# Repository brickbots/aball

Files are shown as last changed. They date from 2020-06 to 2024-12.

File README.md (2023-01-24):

# aball
aball - A Buttonless trackball for all

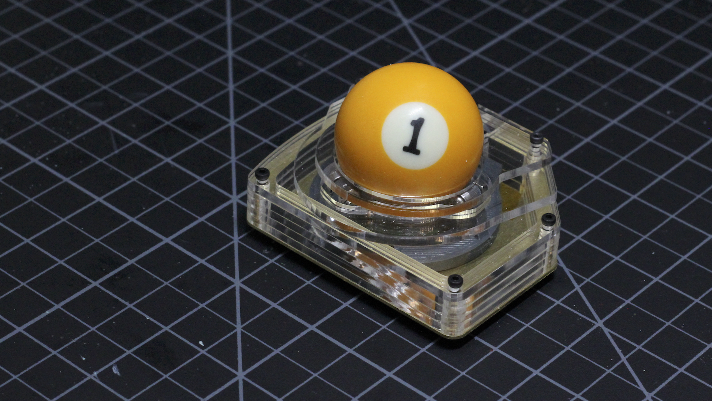
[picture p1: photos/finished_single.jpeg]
aball image The aball


## A trackball with no buttons?
I like keyboards, and my workflow is defintely *keyboard first*.  Tiling window manager, VIM, bash... pretty 
much all the keyboard I can get.  Yet, however hard I try, there is always some need for a pointing device.  
So this is my stab at a trackball for keyboard first workflows.

Why not a mouse?  Well, space... trackballs take up less space.  Which got me thinking, what is the minimum 
footprint for a usable trackball?  I managed to get it down to 60x80mm... you could go even smaller, but I 
wanted some sort of case on it and this particular size sits nicely next to my daily driver, the [Kyria](https://blog.splitkb.com/blog/introducing-the-kyria).

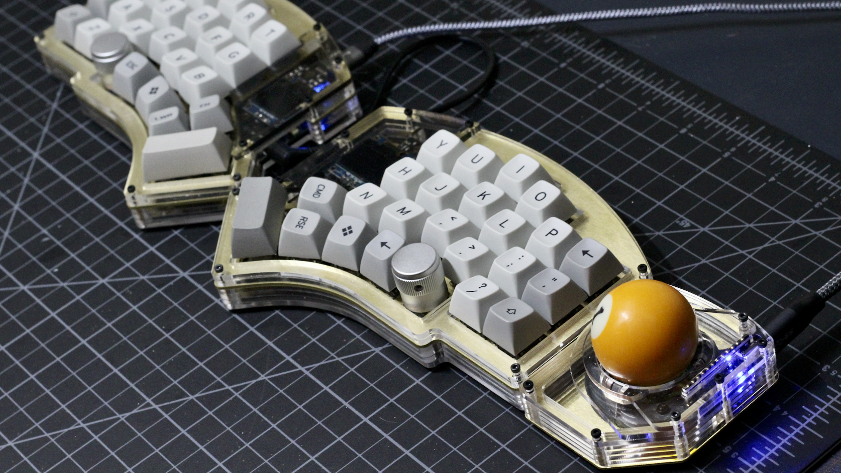
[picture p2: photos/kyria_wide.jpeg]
aball beside Kyria aball with Kyria


In the quest to reduce size, I did away with any buttons.  I have plenty of buttons on my keyboard, and my 
left hand is capable of pressing them when I'm using the aball with my right hand.  Via a layer, I've 
mapped buttons on the home row to:
- F: Left Click
- D: Middle Click
- S: Right Click
- G: Scroll Up
- B: Scroll Down

Scroll up and down are not really needed, but they are pretty handy, even when not using the trackball.  

## Design Info / How it works
Aside from having no buttons and being as small as practical, I wanted the aball to be pretty easy to build and
potentially serve as a jumping off point for other designs.  So I kept these things in mind:

* Readily available parts
* Low cost
* Simple to assemble
* Majority 3d printed if desired
* Supports 38 and 34 mm balls

The design is pretty stripped back, here is a shot of the guts which are self supporting and can be used just as is:

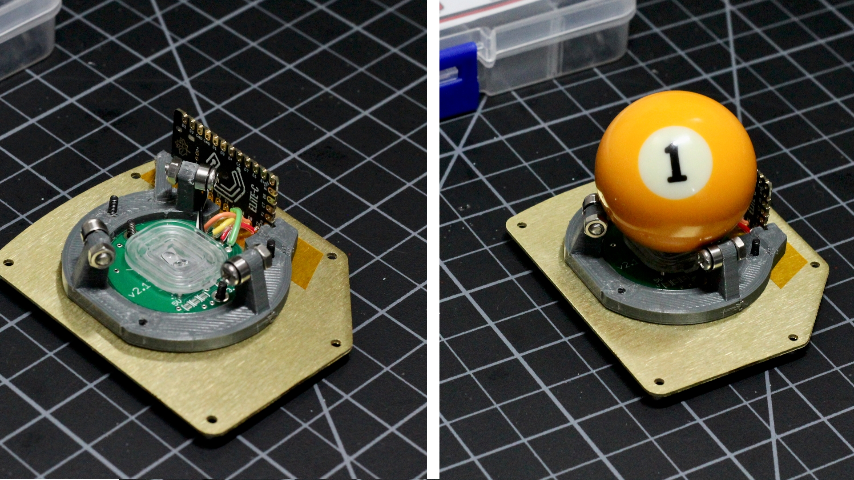
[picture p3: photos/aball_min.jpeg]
aball minimal implementation


The ball sits on a 3d printed frame which holds three roller bearings, and a microcontroller.  The ball moves on top of an optical mouse sensor 
which is connected to the microcontroller. To make the whole thing as close as possible to the desktop, the mouse sensor sticks out
of the bottom of the case, but only a bit and is off the desk due to the rubber feet on the bottom.

### Quick note on roller bearings

If you have not used a trackball with roller bearings before, I think you are in for a treat.  It takes a day or two of good use to 
break them in, but I find them *much* smoother and more enjoyable than static dot type bearings.  You can go cheap here, spending 
less than a dollar for all three of them and they will still be pretty good.  However, a nice set of high quality bearings for RC 
use are not that much more expensive and the quality is definitely higher.

### Firmware

The microcontroller runs firmware based on QMK (Quantum Mechanical Keyboard).  QMK is a fantastic
open source project for keyboard firmware, but it also includes pointing device support.  You can find
the firmware source for the aball here: 
[https://github.com/brickbots/qmk_firmware/tree/aball/keyboards/handwired/aball](https://github.com/brickbots/qmk_firmware/tree/aball/keyboards/handwired/aball)

The minimal implementation is pretty much what you see above and it can be put together for well under $40 if you already have a 3d printer.  From 
there you can either 3d print an enclosure, or use the files here to get some acrylic and metal laser cut for a different look.  I hope that other folks
will adapt these guts and come up with new and clever case options.  Maybe even add buttons on-board :-)

## How can I get one of these?

You can build one yourself!  This repo contains design files, build guides, and a parts list so you can build your own **aball** if you
so choose.  If you do, please drop me a note at rich@brickbots.com.  All information here is provided as-is
for your personal use and is released under a specific Creative Common license which lets you use them for 
non-commercial use.  Please see the included LICENSE file for details.

If you are ready to learn more, or even get started on your own aball, click below to keep exploring

* [Build Guide](./docs/bg_getting_started.md)
* [Parts list (BOM)](./docs/bom.md)

Thanks and email with any questions to suggestions!

<a href='https://ko-fi.com/brickbots' target='_blank'>Buy Me a Coffee at ko-fi.com

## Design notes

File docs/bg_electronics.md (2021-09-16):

# Buile Guide - Electronics

* [Getting Started](../docs/bg_getting_started.md)
* Electronics
* [Structural Assembly](../docs/bg_structure.md)
* [Acrylic Case](../docs/bg_case_acrylic.md)
* [Printed Case](../docs/bg_case_printed.md)
* [Plate Case](../docs/bg_case_plate.md)
* [Parts list (BOM)](../docs/bom.md)

To keep oriented during througout this guide, here is a photo of everything put together without the case.

aball minimal implementation

## Electronics

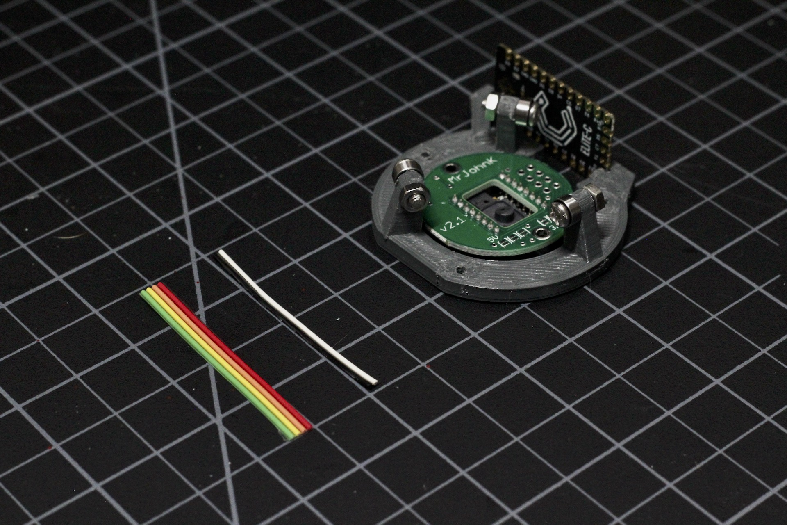
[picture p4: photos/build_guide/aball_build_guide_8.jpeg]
Electronics Arrangement

There are only the two main components and they are connected with just six wires in two groups.  There are two wires for power, and four which carry the SPI interface lines.  

Note the orientation of the MCU and sensor here.  The wires are coming out the BACK of the MCU, and go into the sensor side of the breakout board.

I suggest connecting your MCU and flashing it with the firmware before you start assembly.  This will let you know that it's functional before you spend time soldering.

### Microcontroller

Any pro-micro compatible will work, in this build I'm using an Elite-C as it has a nice robust USB-C connector.  If you do choose something else, you'll need to work out some way to reset the unit. The Elite-C has an onboard reset button and the cases here
have access holes in the proper place to get at it with the case on.  The opening around the plug may also need adjusting, but it should work with many Micro-USB cables if that is what you decide to use.

### Sensor Voltage

If you are using a pro-micro or compatible, it's probably running at 5v.  By default, the sensor
unit is setup to run at 3.3v.  Here is an image, and the description from the vendors website:

Voltage Selection Voltage selection

If you are using Arduino or another similar microcontroller that has a native 5V core voltage, you'll need to activate 5V mode by cutting the tiny traces between the three sets of exposed pads on the 3.3V side of the board and adding three solder bridges to the exposed pads on the 5V side of the board. I recommend an exacto knife. Please be careful not to cut any other nearby traces. Both sets of pads can be found on the backside of the circuit board. This is the most common issue that causes non-communication.

### Wiring

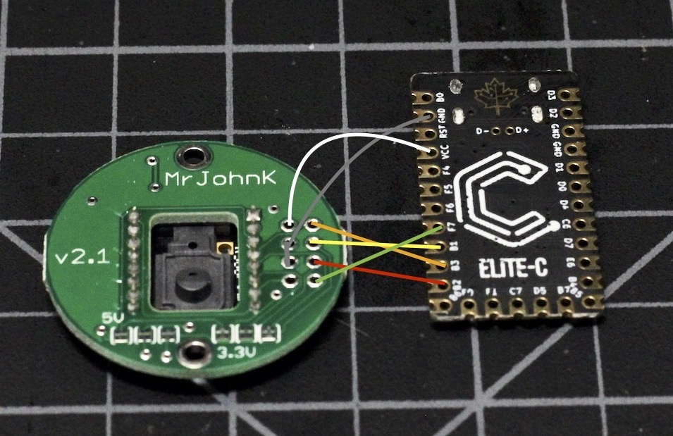
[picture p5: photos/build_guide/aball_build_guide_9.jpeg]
Wiring Wiring Diagram


The diagram above shows the correct connections to make and the suggested pins to use.

* White: VCC +5v
* Grey: Ground.  Note that this is bridged between the analog and digital ground on the sensor
* Red, Orange, Yellow: SPI Bus connections, these can't be relocated
* Green: Select line... any digital pin will do but this is the most convineint location.

You can see the routing of the wires in the image at the top of this page. I suggest stripping both ends of the wires before starting to solder them.  You have some room to work, but keeping the wires short-ish is helpful.  You'll have to solder these wires from the top side sticking out the back of the MCU.

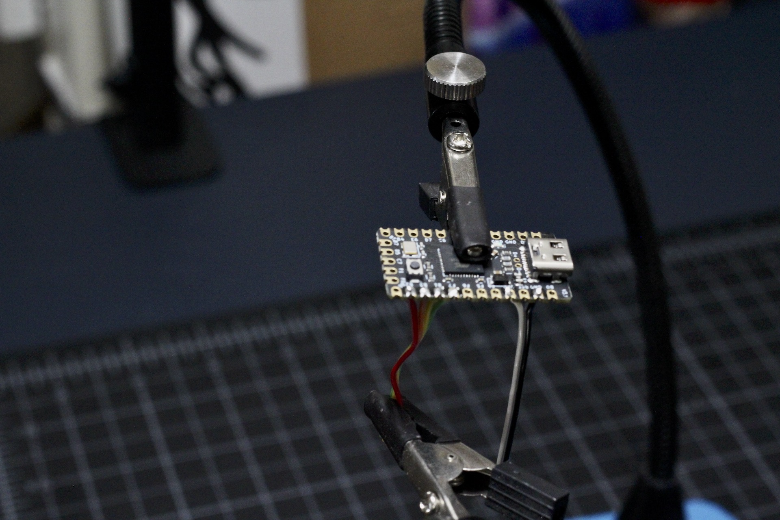
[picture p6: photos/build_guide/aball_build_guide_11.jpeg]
Soldering Soldering from the top


Here is a photo after all the wires attached to the MCU, with a ruler to show how long I made them.

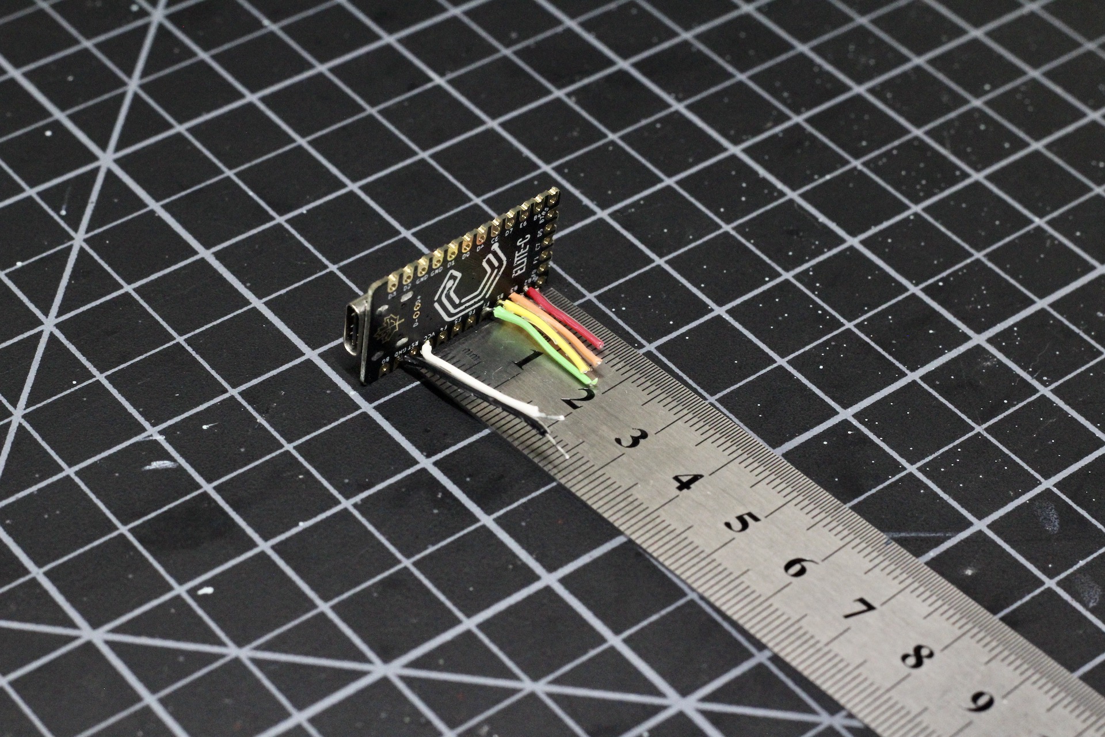
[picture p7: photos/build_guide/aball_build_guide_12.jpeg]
Wire Length Wires for length


Make sure you have the sensor oriented correctly, and follow the wiring diagram to connect the wires to the MCU and finish this step up.

### Testing

This is a great time to plug the MCU back into your computer.  You can place the lens on top of the sensor unit and just run your finger over the sensor.  You should see the cursor on screen move.  If so, you are all set to go with the mechanical assembly!

* [Structural Assembly](../docs/bg_structure.md)

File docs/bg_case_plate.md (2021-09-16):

# Build Guide - Plate Case

* [Getting Started](../docs/bg_getting_started.md)
* [Electronics](../docs/bg_electronics.md)
* [Structural Assembly](../docs/bg_structure.md)
* [Acrylic Case](../docs/bg_case_acrylic.md)
* [Printed Case](../docs/bg_case_printed.md)
* Plate Case
* [Parts list (BOM)](../docs/bom.md)

To keep oriented during througout this guide, here is a photo of everything put together without the case.

aball minimal implementation

### Parts List

For the plate version of the case, you'll need three pieces in total.  You can find all the .dxf
files in the /case/laser_cut_plate. You can use metal, acrylic, wood... basically any material.  1.5mm
thickness works great, but you can go a bit thicker/thinner and everything should still work.

* 1 x middle.dxf
* 1 x top.dxf
* 1 x bottom.dxf

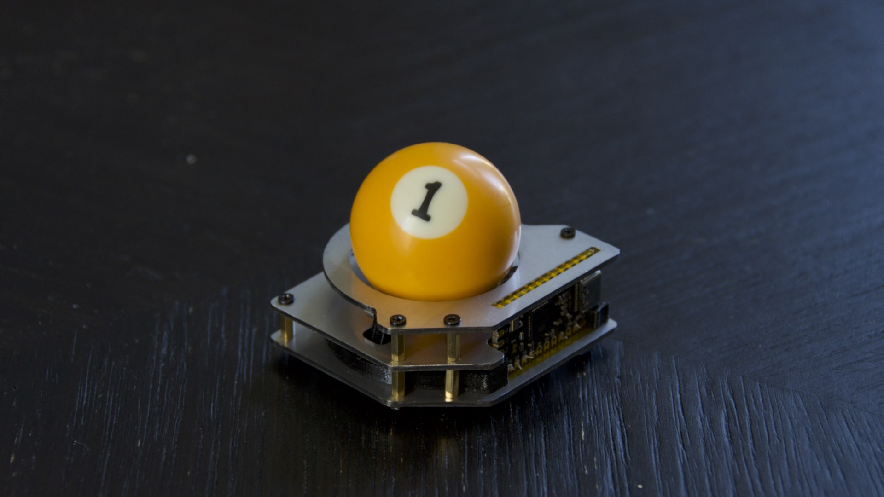
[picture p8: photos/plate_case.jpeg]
Plate Case Sooo metallic!


You'll need m2 standoffs and screws.  The middle layer must be put in plate BEFORE the bearings!  It's 
also much easier to install the lens before the middle layer is installed.

*NOTE:* Don't forget to use insulating tape on the Elite-C along the top 
and on the bottom plate to prevent shorting!

There ya go! Drop in the ball and plug it in.  Feel free to 
contact me with any questions on building, flashing or aquiring parts.  If you do build on of these
I'd love to see it.

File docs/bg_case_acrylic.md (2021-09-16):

# Build Guide - Acrylic Case

* [Getting Started](../docs/bg_getting_started.md)
* [Electronics](../docs/bg_electronics.md)
* [Structural Assembly](../docs/bg_structure.md)
* Acrylic Case
* [Printed Case](../docs/bg_case_printed.md)
* [Plate Case](../docs/bg_case_plate.md)
* [Parts list (BOM)](../docs/bom.md)

To keep oriented during througout this guide, here is a photo of everything put together without the case.

aball minimal implementation

### Parts List

For the acrylic version of the case, you'll need seven 3mm layers in total, not including the base piece
which can either be 3d printed using the STL in the /case/printed directory, or laser cut from 1.5mm 
metal or acrylic.
You can find all the .dxf
files in the /case/laser_cut_stacked directory.  I use Ponoko, and these files are already scaled 
and ready to go.  

If you use elite-c MCU's there is a reset button on the top of the board.  These cases have an 
access hole to reach this button from the side.  That's the reason for the two different 
middle layers.  If you don't want this hole, just use four of the layer A's.  Here is the cut list 
for the cases as pictured with reset hole:

* 2 x middle_a.dxf - Middle piece with no side hole
* 2 x middle_b.dxf - Middle piece with side reset hole
* 1 x top_a.dxf
* 1 x top_b.dxf
* 1 x top_c.dxf

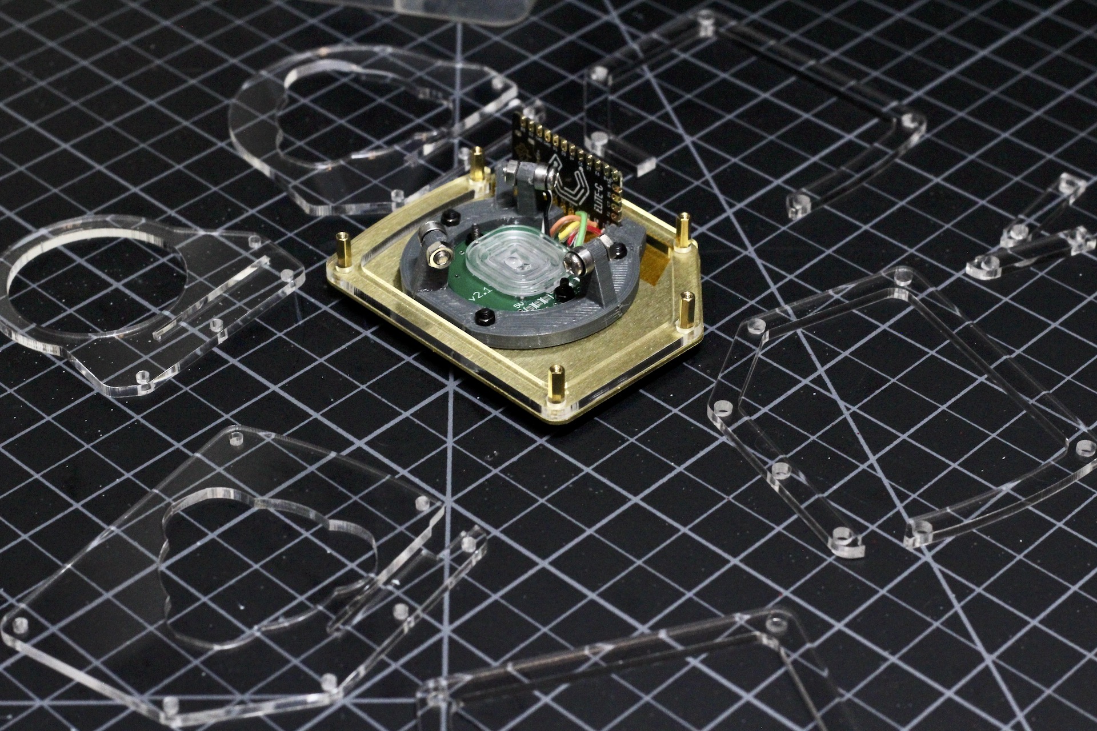
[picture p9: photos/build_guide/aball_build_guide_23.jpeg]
Layers everywhere Layers, Layers!


Peel any protective film off the pieces and stack them up!  Put the two middle_b pieces between the two
middle_a pieces and the gap should line up with the reset button on the MCU.  Use the various screw lengths to
secure the layers.  

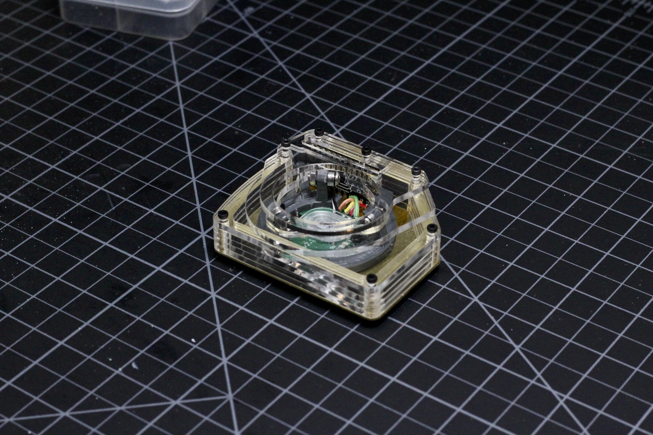
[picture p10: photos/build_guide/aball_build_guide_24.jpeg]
All Built All done


There ya go!  Make sure you seat the lens properly, drop in the ball and plug it in.  Feel free to 
contact me with any questions on building, flashing or aquiring parts.  If you do build on of these
I'd love to see it.

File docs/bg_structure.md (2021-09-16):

# Build Guide - Structural Assembly

* [Getting Started](../docs/bg_getting_started.md)
* [Electronics](../docs/bg_electronics.md)
* Structural Assembly
* [Acrylic Case](../docs/bg_case_acrylic.md)
* [Printed Case](../docs/bg_case_printed.md)
* [Plate Case](../docs/bg_case_plate.md)
* [Parts list (BOM)](../docs/bom.md)

To keep oriented during througout this guide, here is a photo of everything put together without the case.

aball minimal implementation

### Print Frame

You'll need to print one of the vertical_frame files depending on your micro controller and ball size:
* vertical_frame_rev3_38mm.stl - For 1.1mm thick MCUs (such as the Elite-C rev3 or clone pro-micros) and a 38mm ball.  This is what the prototype is based on and is pictured in the build guide.
* vertical_frame_rev4_38mm.stl - For 1.6mm thick MCUs (such as the Elite-C rev4) and a 38mm ball
* vertical_frame_rev4_38mm.stl - For 1.6mm thick MCUs (such as the Elite-C rev4) and a 34mm ball

It lays flat on the bed and will not require any supports.  It's
pretty small, so you might as well go 100% infill.  Depending on your print quality, you might need to drill out the
holes to fit the screws through.  

### Mount Bearings

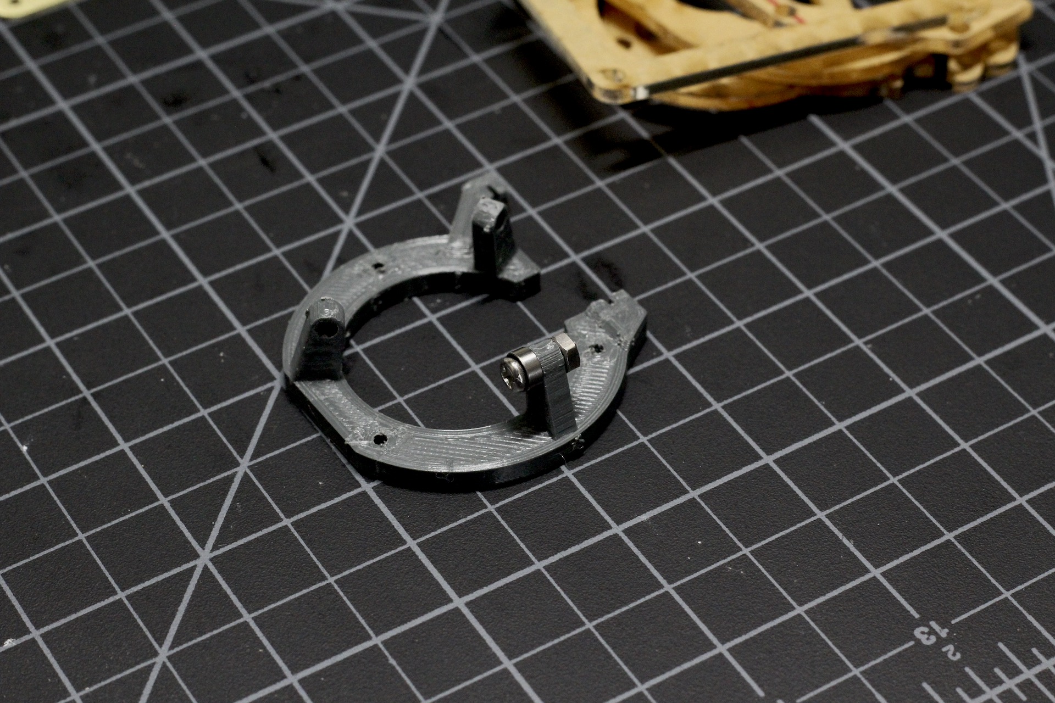
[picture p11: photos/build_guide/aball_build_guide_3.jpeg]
Partially Mounted Bearings Mounted Bearings


Use the M3 round head bolts and nuts to secure the bearings to the frame.  The mount for each bearing is offset so that 
the roller bearings contact the ball properly.  Each bearing needs to be mounted on the clockwise side of the support.
Check the photos if you have any questions.  You can secure these finger tight.

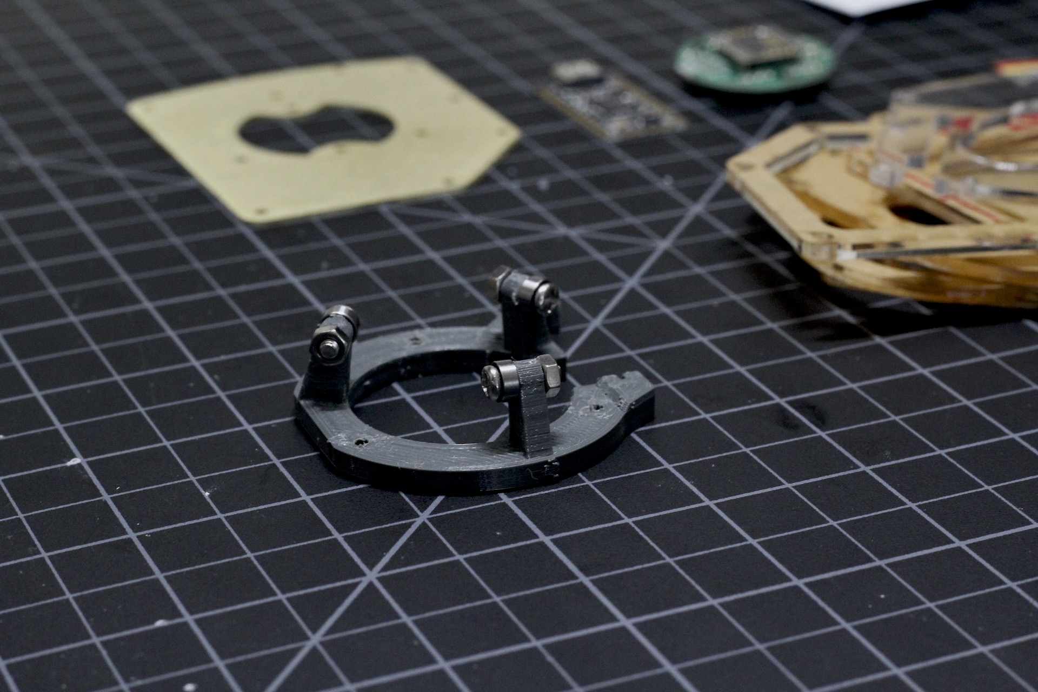
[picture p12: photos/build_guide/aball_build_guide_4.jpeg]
Mounted Bearings


Once they are in place, set the ball on top and everything should roll pretty smoothly.  

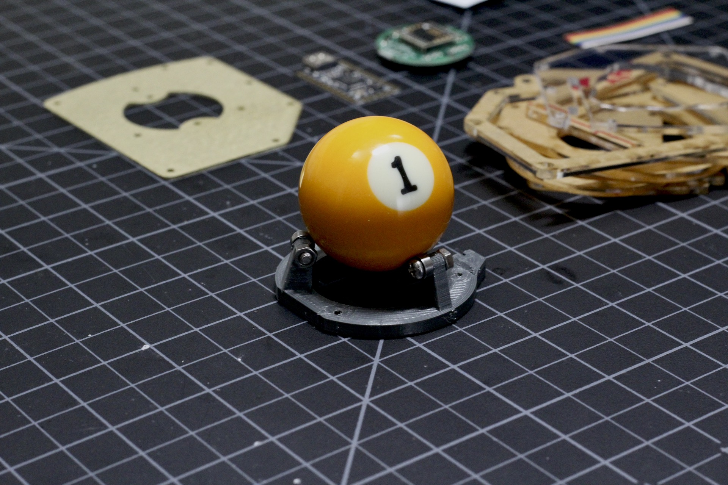
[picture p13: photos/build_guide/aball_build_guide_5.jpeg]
Testing the roll


You can adjust the tightness of the nuts if they are binding.  The bearings will take some time to break in,
so don't be too concerned if they are a bit scratchy, just check that they roll freely.

### Prepare the base

For the base, you can either 3d print the file bottom.stl in the case/printed folder or get the bottom laser 
cut from metal using the bottom.dxf in either of the case/laser_cut folders.  It should be about 1.5mm thick either way.  Since the sensor sticks out of
bottom of the case slightly to reduce to overall height, you'll need to put feet on it before continuing assmbly.

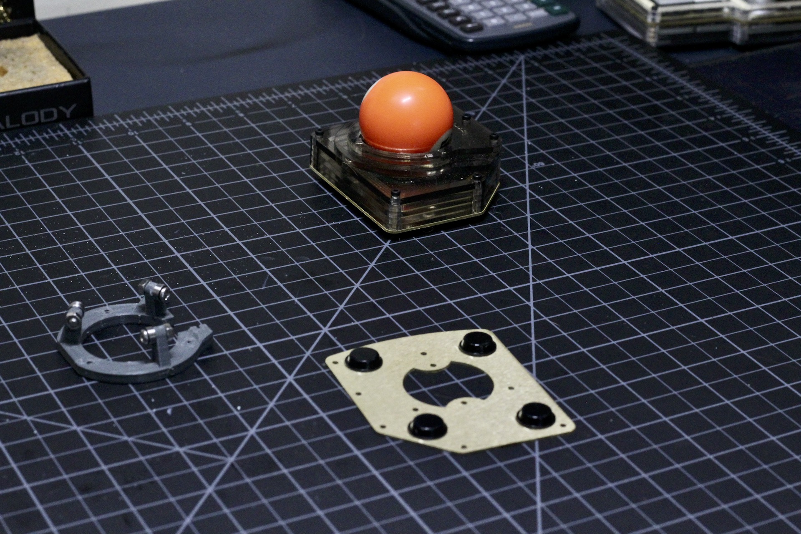
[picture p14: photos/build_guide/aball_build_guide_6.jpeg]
Feet Placement Feet placement


If you are using a metal base, it's a good idea to put down a layer of insulation using either Kapton or electrical tape.  Here's
a photo showing the areas where contact might happen and that should be insulated.  

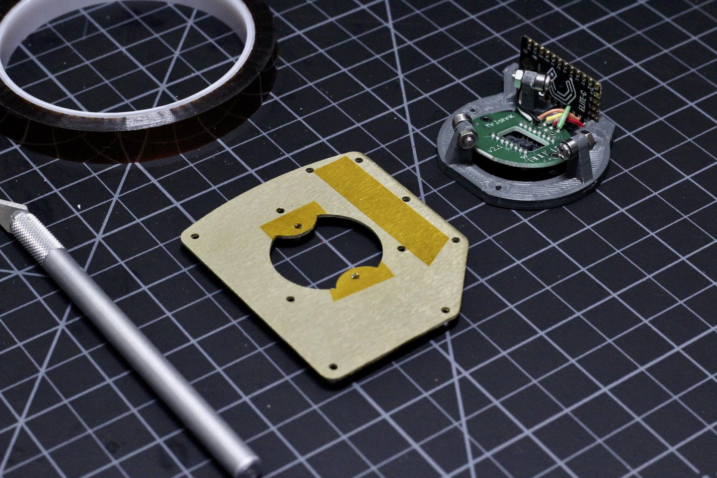
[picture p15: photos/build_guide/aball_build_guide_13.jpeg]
Insulation Tape Placement


### Fit the MCU to the frame

The MCU should friction fit in the slots as show in the photo above and the detail below.  Depending on your printer, you might
need to file these slightly.  You can see above how I routed the wires, but it depens on how long you ended up making them.  

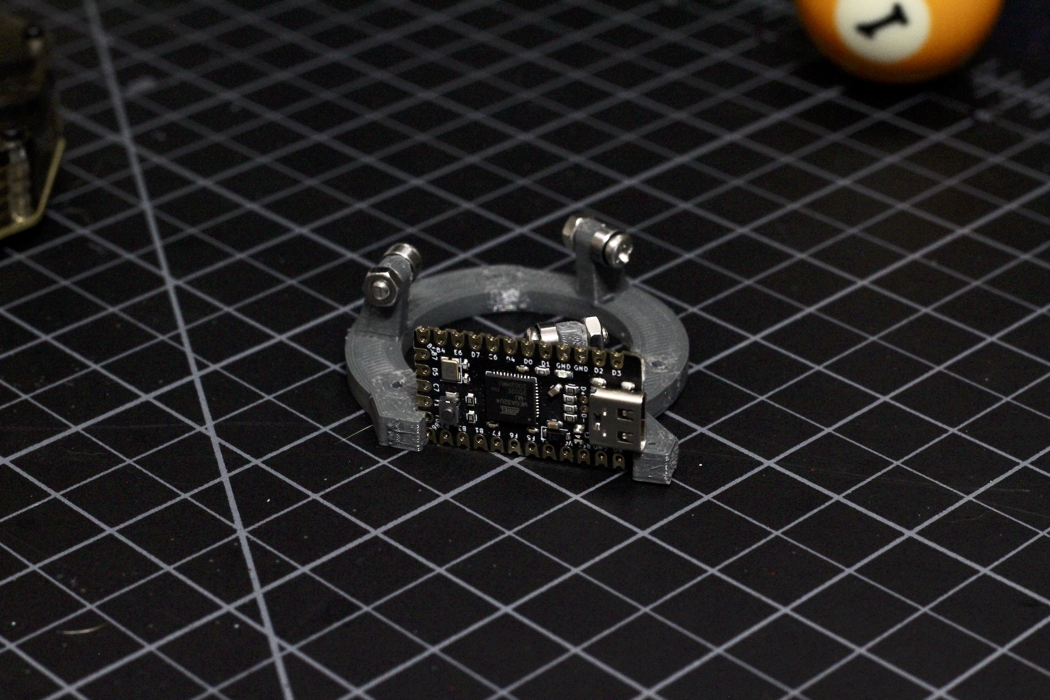
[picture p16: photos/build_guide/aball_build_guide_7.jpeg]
MCU Fitment MCU Fitted on the frame


### Secure the Frame / Sensor

Both the frame and the sensor mount on bolts inserted from the bottom.  The length is not overly critical here, just make sure
they are not soooo long that they rub on the ball.  Use the nuts to secure everything together.  The photo below shows the 
three bolts that hold the frame and the two bolts that hold the sensor.

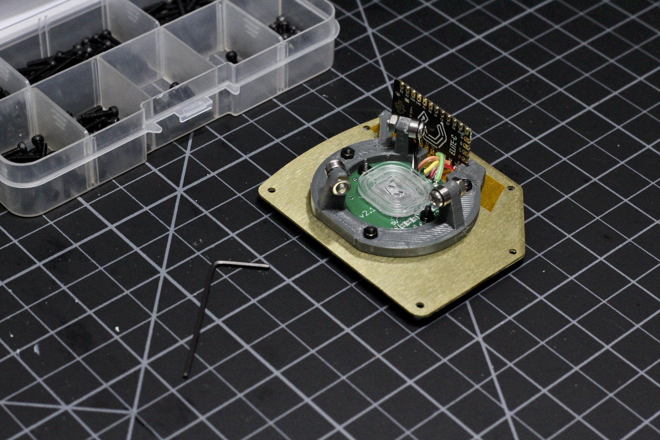
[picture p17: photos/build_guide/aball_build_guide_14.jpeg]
Bolt it together


### Prep for the case

No matter which case you use, it's supported/aligned with seven 10mm standoffs.  You can either use the
male/female ones pictured below or you can use the double female ones either work.  You'll want to secure
these to the bottom plate in the provided holes.

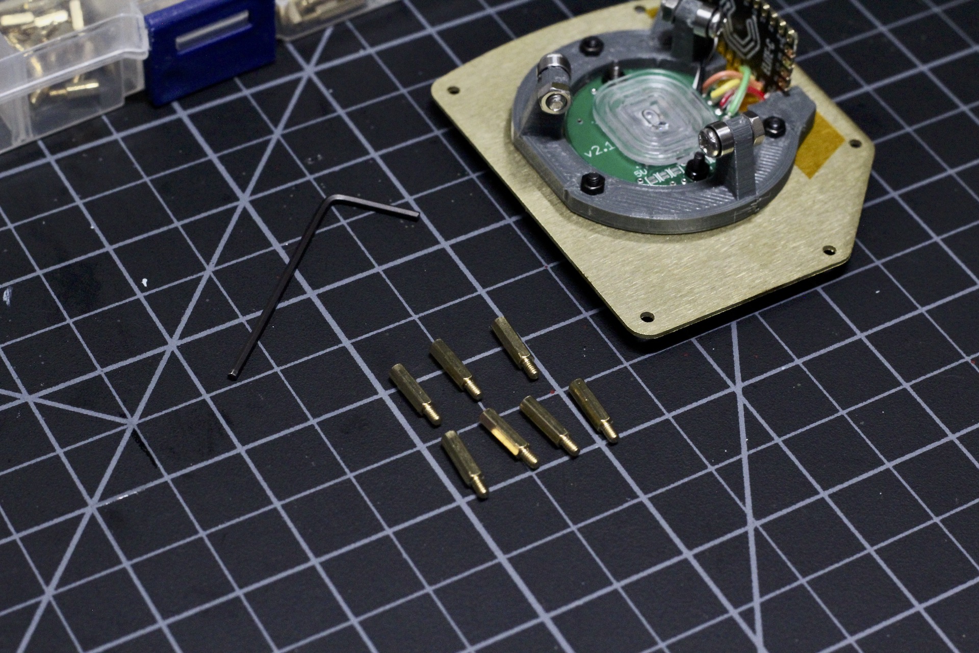
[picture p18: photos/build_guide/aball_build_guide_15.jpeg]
Standoff Setup Standoffs


Here is a view of the underside with the standoffs secured with nuts.

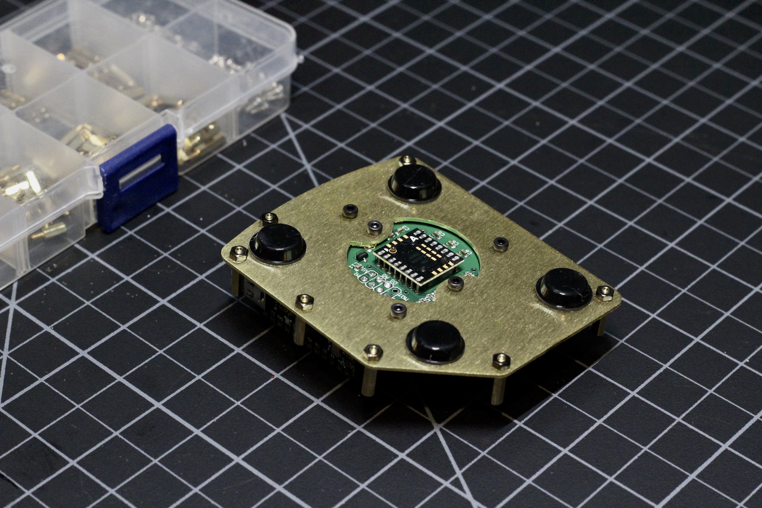
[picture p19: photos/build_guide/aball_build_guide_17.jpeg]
Secured with nuts


Now the structure is done and the case is ready to be installed. 

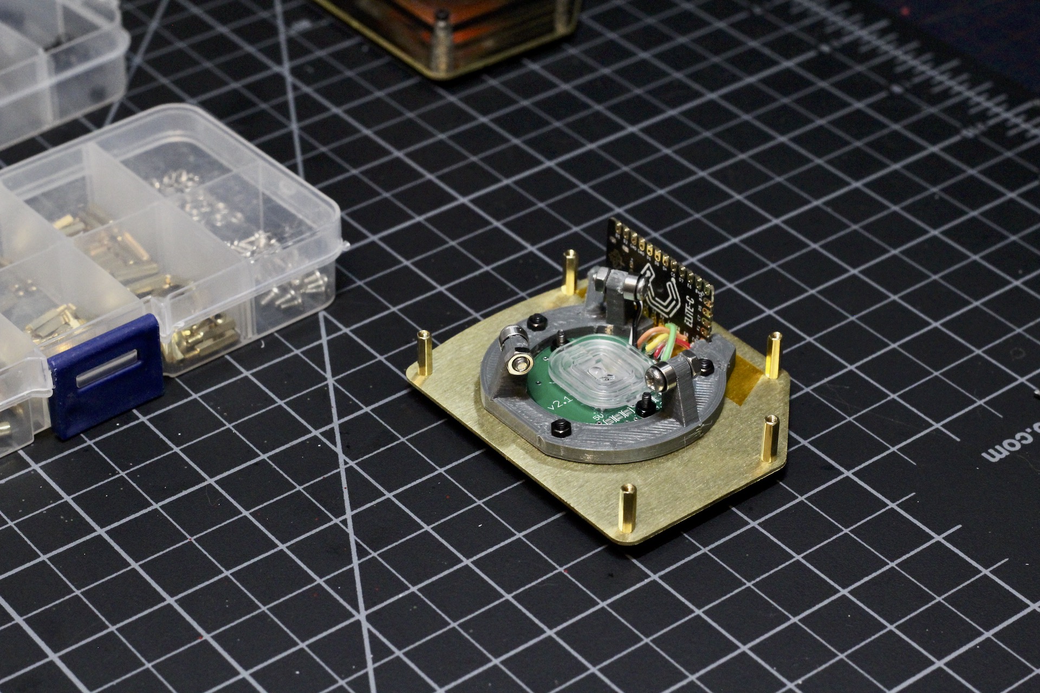
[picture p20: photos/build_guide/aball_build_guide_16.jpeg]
Ready for case Ready for case!


There are two case options available:
* [Acrylic Case](../docs/bg_case_acrylic.md)
* [Printed Case](../docs/bg_case_printed.md)

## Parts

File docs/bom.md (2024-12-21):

# aball - Parts List / BOM

## Minimal Parts List
If you don't want any case at all, here is the stuff you'll need for the guts of an aball.  You'll need to 3d print
the support frame and some sort of bottom if you don't want to use metal.

Quantity|Item|URL
---|---|---
3|3x6x2.5mm Ball Bearing|https://www.amazon.com/gp/product/B014LT87HS
3|M3 Nuts|
3|M3 Bolts, round head, 10mm|
5|M2x8 Bolts|
5|M2 nuts |
3|Rubber Feet|
1|Pro Micro Compatible - Elite-C Recommended|
1|ADNS-9800 Laser Motion Sensor Breakout|https://www.tindie.com/products/citizenjoe/adns-9800-motion-sensor/
1|Ball either 38mm or 34mm|https://www.amazon.com/gp/product/B00CEQY0J0 https://www.amazon.com/gp/product/B07BDGSX5X

## Acrylic / Printed case
There are plans in this repo for both a 3d printed, and laser cut acrylic case.  Depending on what case you want, and what you have on hand,
you can substitute some of the M2 hardware.  

Quantity|Item|URL
---|---|---
3|3x6x2.5mm Ball Bearing|https://www.amazon.com/gp/product/B014LT87HS
3|M3 Nuts|
3|M3 Bolts, round head, 10mm|
5|M2x8 Bolts|
4|M2x12 Bolts|
3|M2x6 Bolts|
7|M2 standoff M/F 10mm|
12|M2 nuts |
3|Rubber Feet|
1|Pro Micro Compatible - Elite-C Recommended|
1|Jack Enterprises - ADNS-9800 Laser Motion Sensor Breakout|https://www.tindie.com/products/jkicklighter/adns-9800-laser-motion-sensor/
1|Ball either 38mm or 34mm|https://www.amazon.com/gp/product/B00CEQY0J0 https://www.amazon.com/gp/product/B07BDGSX5X

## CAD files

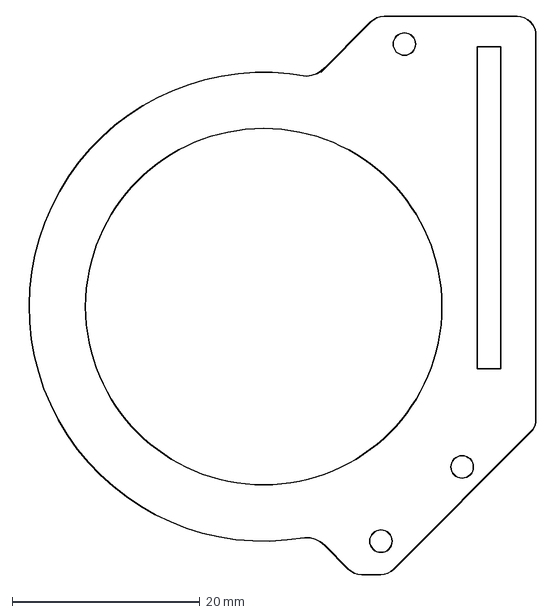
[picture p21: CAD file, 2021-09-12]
case/laser_cut_plate/top.dxf
55.4 x 59.5 mm

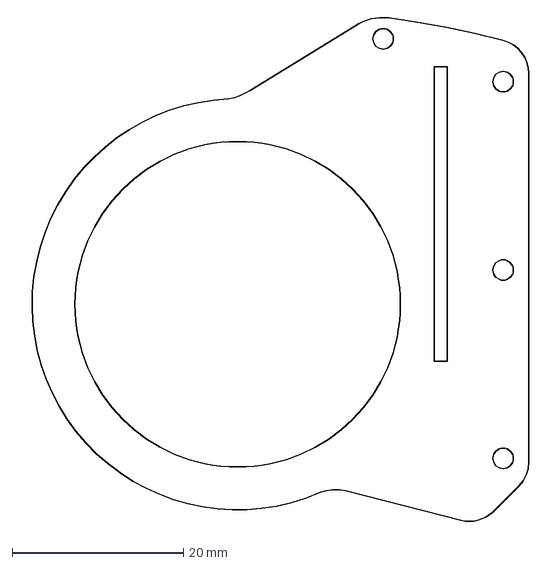
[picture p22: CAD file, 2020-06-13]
case/laser_cut_stacked/top_c.dxf
59.9 x 59.5 mm

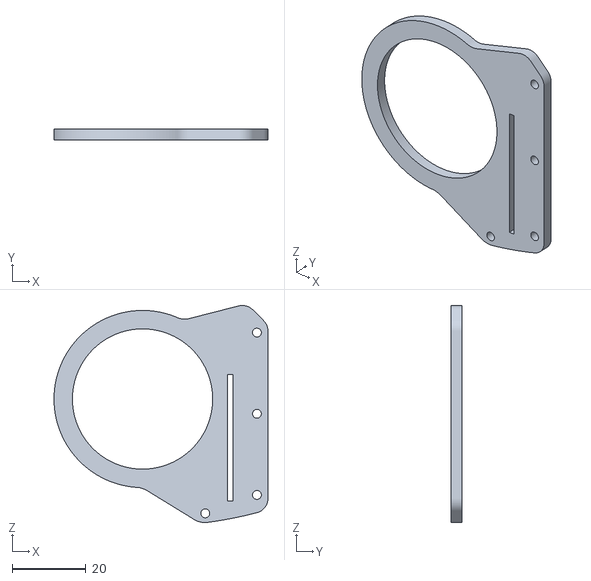
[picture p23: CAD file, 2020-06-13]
case/printed/top_c.stl
58.0 x 2.90 x 58.8

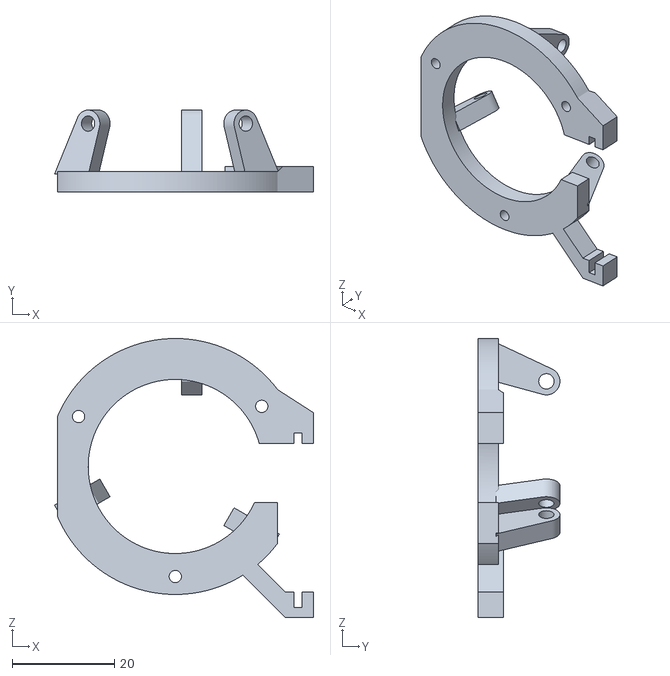
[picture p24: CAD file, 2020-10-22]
vertical_frame_rev4_34mm.stl
50.6 x 16.0 x 54.5

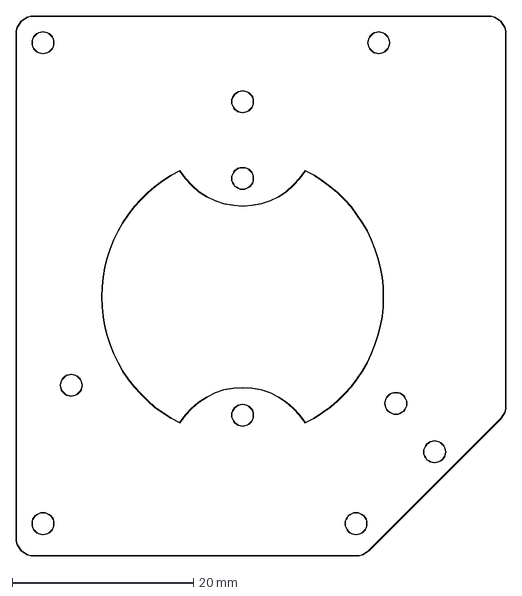
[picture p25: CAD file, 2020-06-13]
case/laser_cut_plate/bottom.dxf
54.0 x 59.5 mm

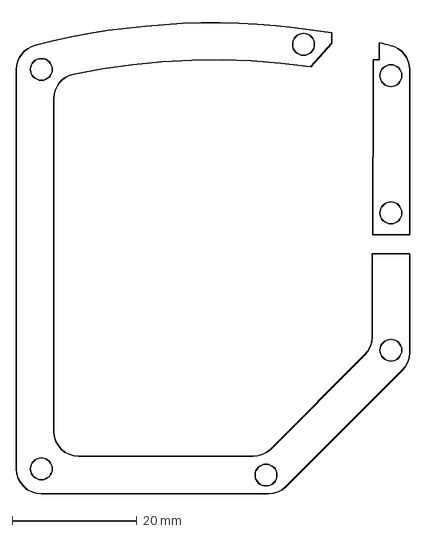
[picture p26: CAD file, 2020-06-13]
case/laser_cut_stacked/middle_b.dxf
63.0 x 76.5 mm

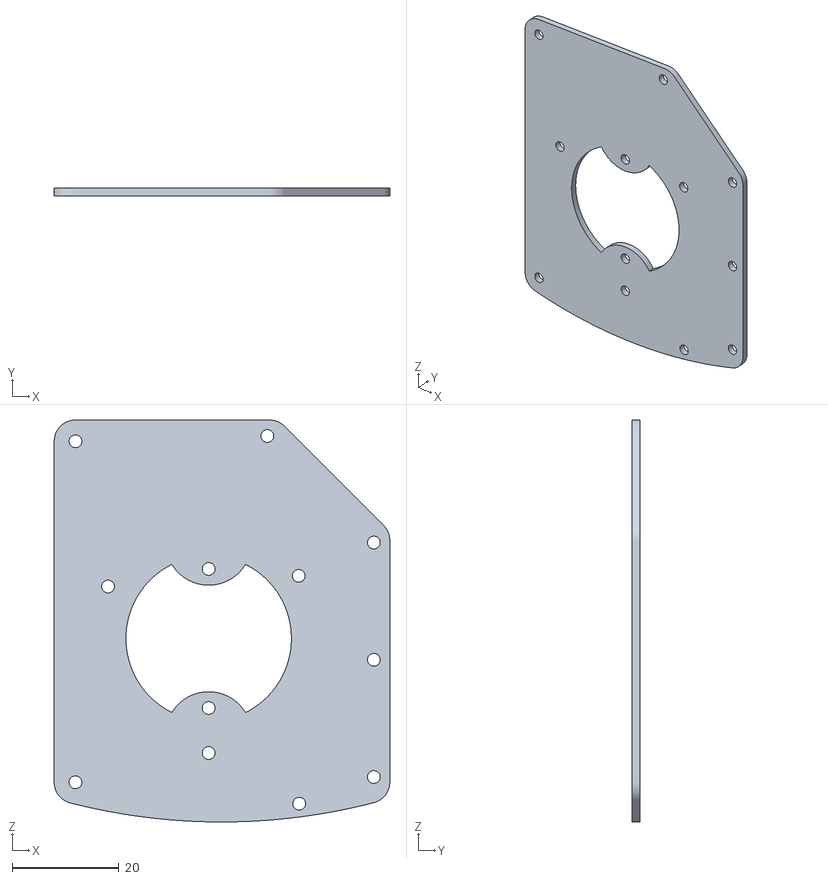
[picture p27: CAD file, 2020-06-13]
case/printed/bottom.stl
63.0 x 1.50 x 75.4

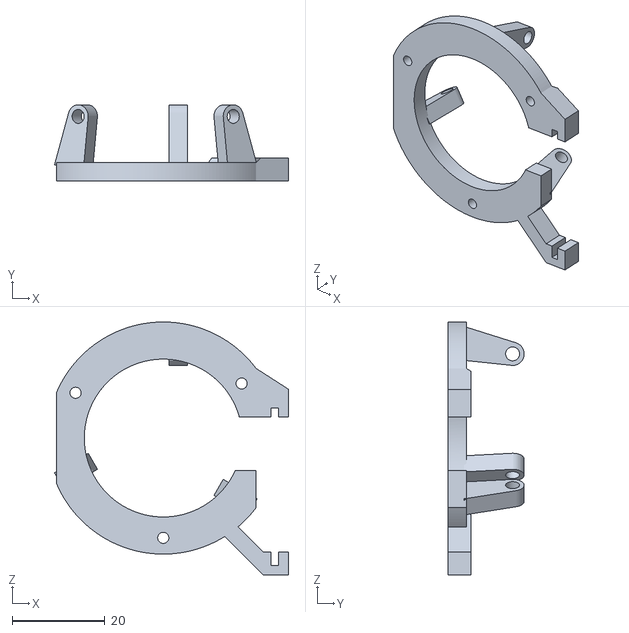
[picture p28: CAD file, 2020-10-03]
vertical_frame_rev4_38mm.stl
50.5 x 16.4 x 54.5

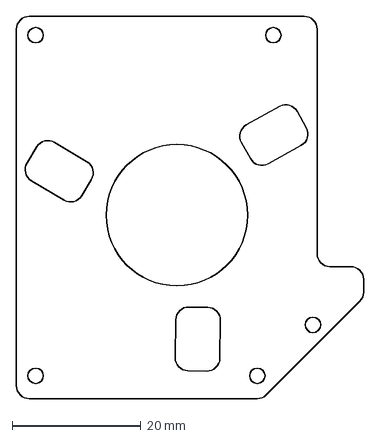
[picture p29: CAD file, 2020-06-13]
case/laser_cut_plate/middle.dxf
54.0 x 59.5 mm

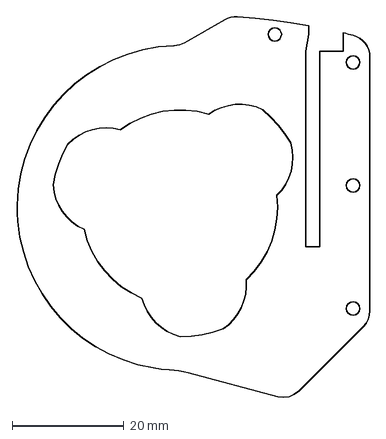
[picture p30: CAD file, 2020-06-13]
case/laser_cut_stacked/top_b.dxf
63.2 x 68.3 mm

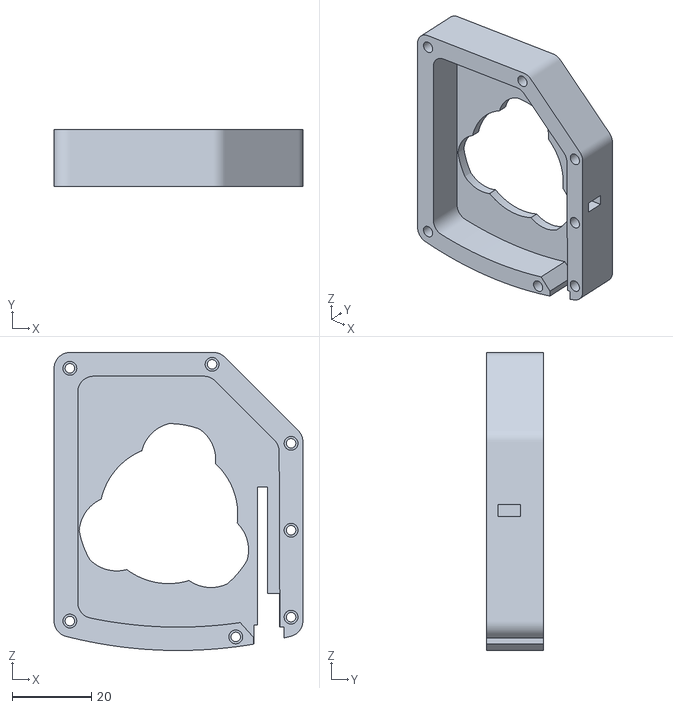
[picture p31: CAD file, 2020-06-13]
case/printed/middle_top_a.stl
63.0 x 14.5 x 75.4

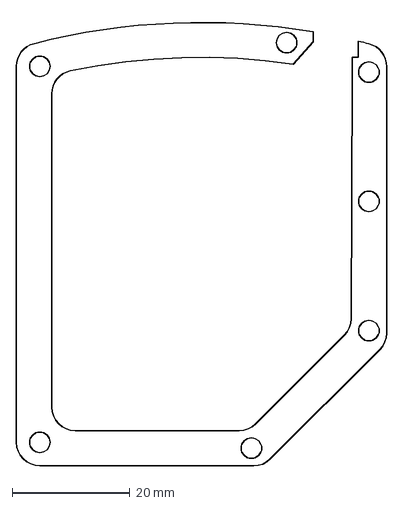
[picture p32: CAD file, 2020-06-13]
case/laser_cut_stacked/middle_a.dxf
63.0 x 76.5 mm

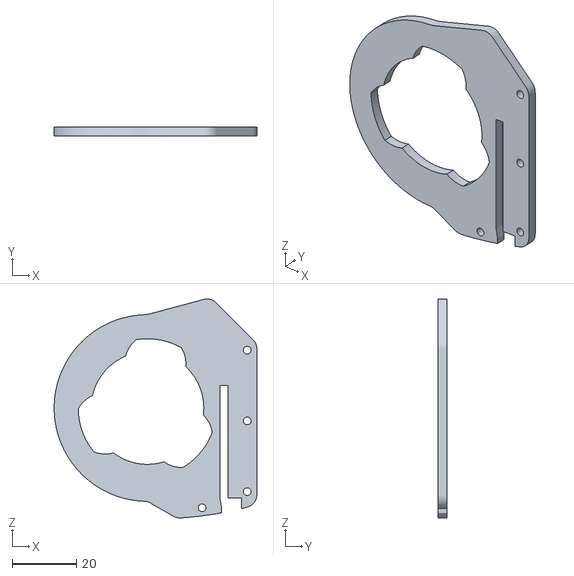
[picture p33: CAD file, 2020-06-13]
case/printed/top_b.stl
63.0 x 2.90 x 68.1

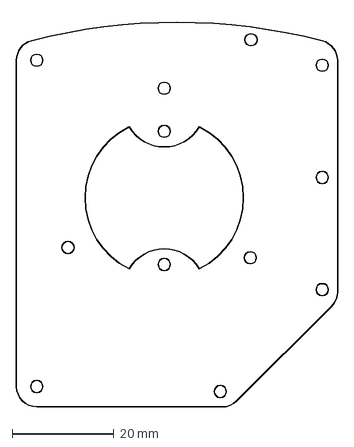
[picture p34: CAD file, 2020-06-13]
case/laser_cut_stacked/bottom.dxf
63.0 x 76.7 mm

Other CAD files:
case/laser_cut_stacked/top_a.dxf
vertical_frame_rev3_38mm.stl
aball_v15.f3d

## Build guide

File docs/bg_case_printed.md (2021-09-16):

# Build Guide - Printed Case

* [Getting Started](../docs/bg_getting_started.md)
* [Electronics](../docs/bg_electronics.md)
* [Structural Assembly](../docs/bg_structure.md)
* [Acrylic Case](../docs/bg_case_acrylic.md)
* Printed Case
* [Plate Case](../docs/bg_case_plate.md)
* [Parts list (BOM)](../docs/bom.md)

To keep oriented during througout this guide, here is a photo of everything put together without the case.

aball minimal implementation

### Parts List

For the printed version of the case, you'll need four pieces in total.  You can find all the .stl
files in the /case/printed.  They should all print easily and don't require supports.  Since they are
pretty much all walls/flat surfaces, you can print with high-infill for weight and it won't take 
much longer.

* 1 x middle_top_a.stl
* 1 x top_b.stl
* 1 x top_c.stl

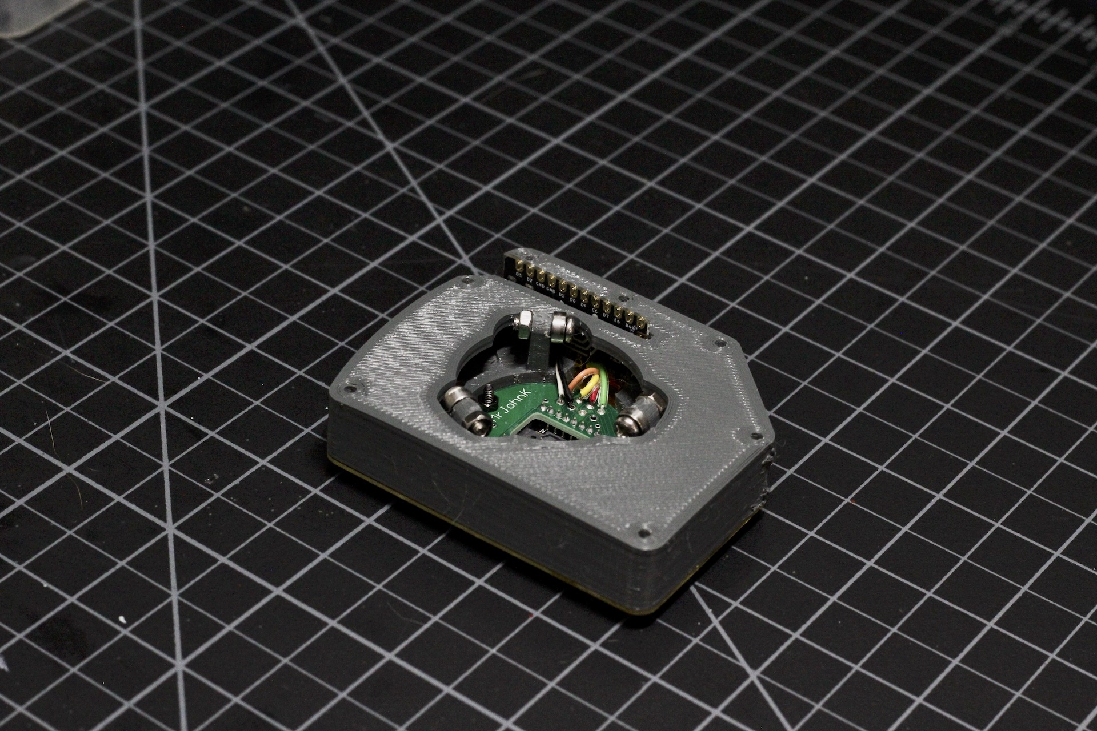
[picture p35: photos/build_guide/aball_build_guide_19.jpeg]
Middle Case Layers, Layers!


The middle_top piece slides over the stand-offs.  Depending on your printer quality/settings 
you might need to drill out some of the holes to the proper diameter.  

To finish up, the two other top pieces stack on top and you can secure everything with the 
various lengths of screws. 

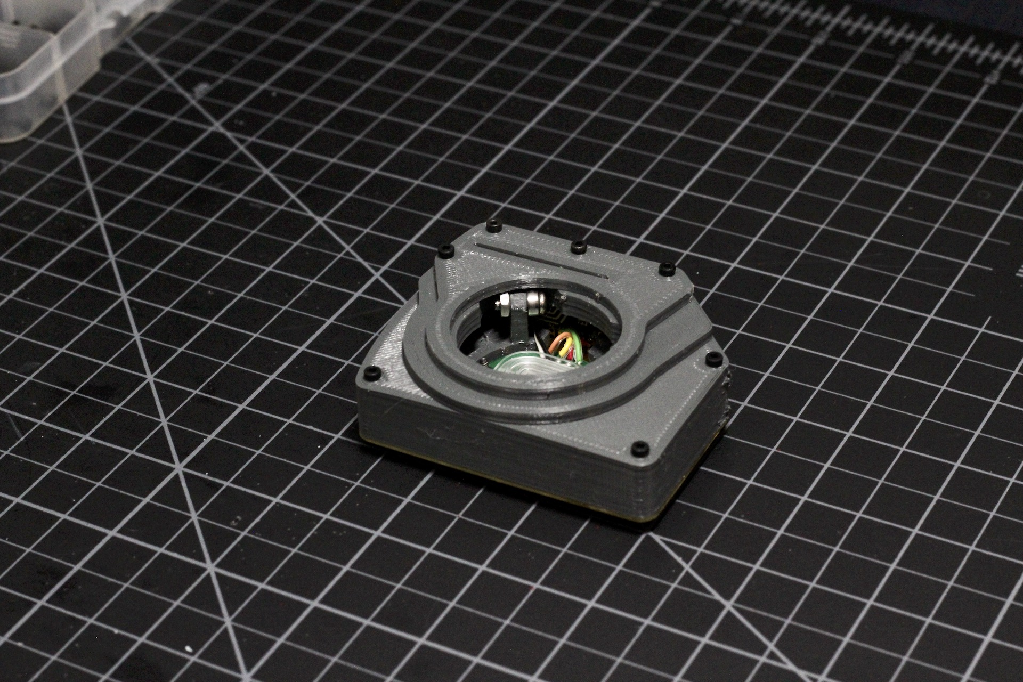
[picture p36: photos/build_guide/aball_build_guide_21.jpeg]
All Built All done


There ya go!  Make sure you seat the lens properly, drop in the ball and plug it in.  Feel free to 
contact me with any questions on building, flashing or aquiring parts.  If you do build on of these
I'd love to see it.

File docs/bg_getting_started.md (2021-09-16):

# Build Guide - Getting Started

* Getting Started
* [Electronics](../docs/bg_electronics.md)
* [Structural Assembly](../docs/bg_structure.md)
* [Acrylic Case](../docs/bg_case_acrylic.md)
* [Printed Case](../docs/bg_case_printed.md)
* [Plate Case](../docs/bg_case_plate.md)
* [Parts list (BOM)](../docs/bom.md)

To keep oriented during througout this guide, here is a photo of everything put together without the case.

aball minimal implementation

## Collect your parts

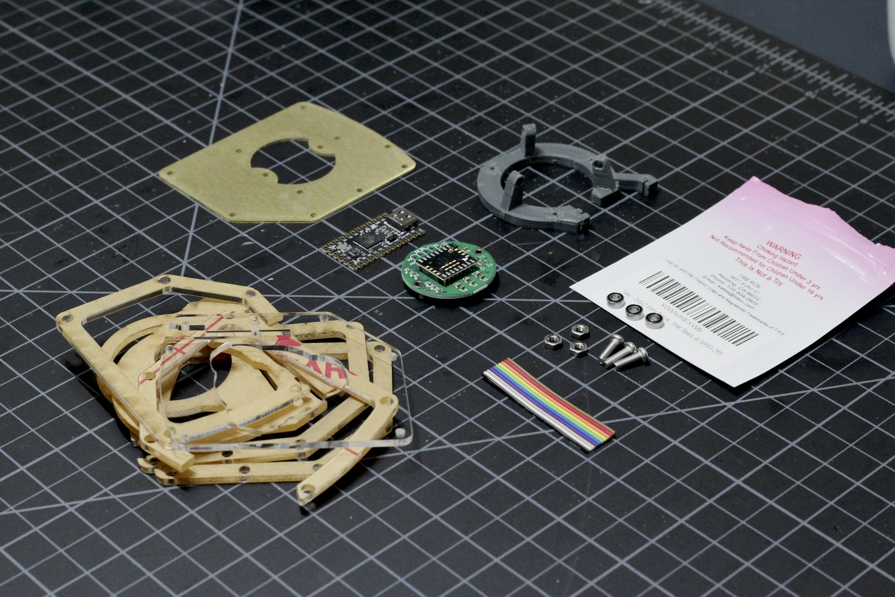
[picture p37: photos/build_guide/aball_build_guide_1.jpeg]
Parts Image The Parts


Here are all the parts required to build an ABall with acrylic case.  See the Parts List above for details.  A case is strictly optional, and I've used protoypes without one....but the bottom plate is essential as it's what everyting else bolts on to.  

In this photo the sensor is upside down, with the lens assembly pointing down.  In most of these other photos 
you'll see this sensor facing upwards, so it can keep an eye on the ball... so to speak.  There is a plastic
lens assembly that only fits on one way.  You don't need to secure this in place at all and you'll see some 
shots with, and some without it.  It's definitely needed for the sensor to work, so don't loose it.

### Bearings and Ball - Your point of contact
I've included information about the bearings in the BOM, but here is a closeup of the ones I prefer.  The price difference is not much for pretty much top of the line, and it's really the biggest determiner of feel apart from the ball itself.  The size I selected is fairly common for RC cars, planes, etc.. so you should be able to find a good variety.

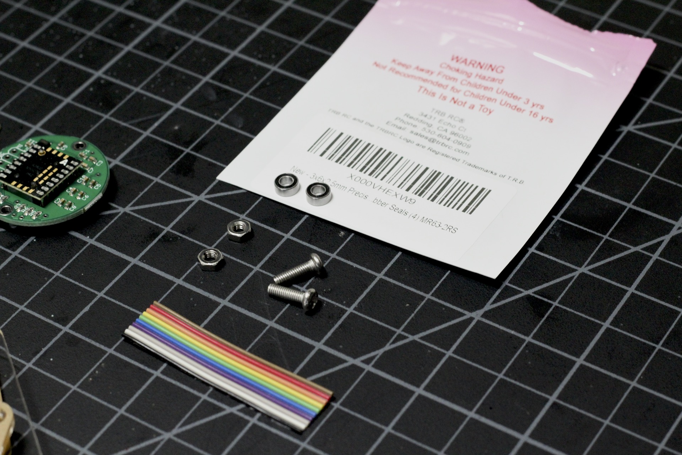
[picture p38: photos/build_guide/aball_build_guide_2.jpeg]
Bearing Closeup RC bearings


As for balls, I've designed this around 38mm balls.  You can go a bit larger, or smaller, and the overall support will work, but cases may not fit properly.  This is a pretty standard size for mini billlard balls, but you an also get full steel ball bearings of this size if you like a heavy roll.  I've tried this, and I can't say I recommend it, but there are plenty of possibilities!  

Now that you have all your pieces together, let's start with the [electronics](../docs/bg_electronics.md)!

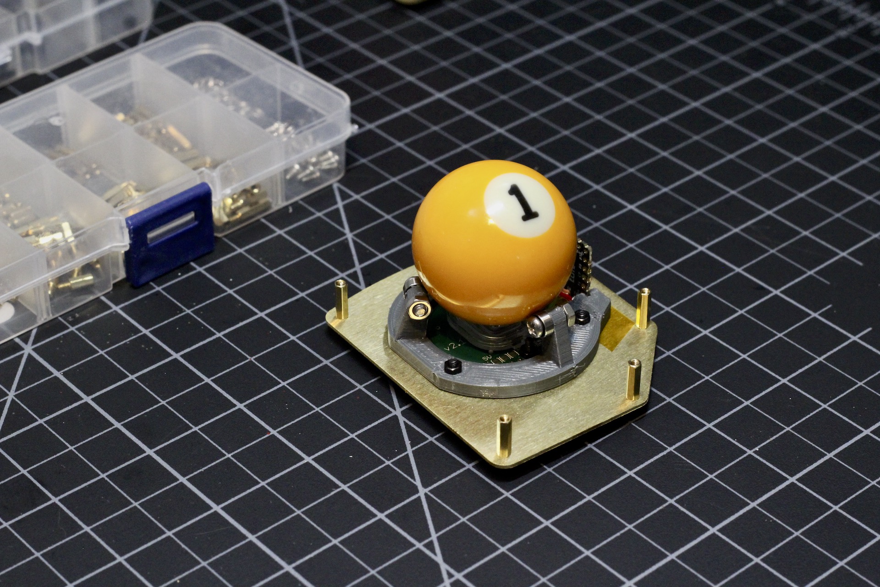
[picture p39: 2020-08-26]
photos/build_guide/aball_build_guide_18.jpeg

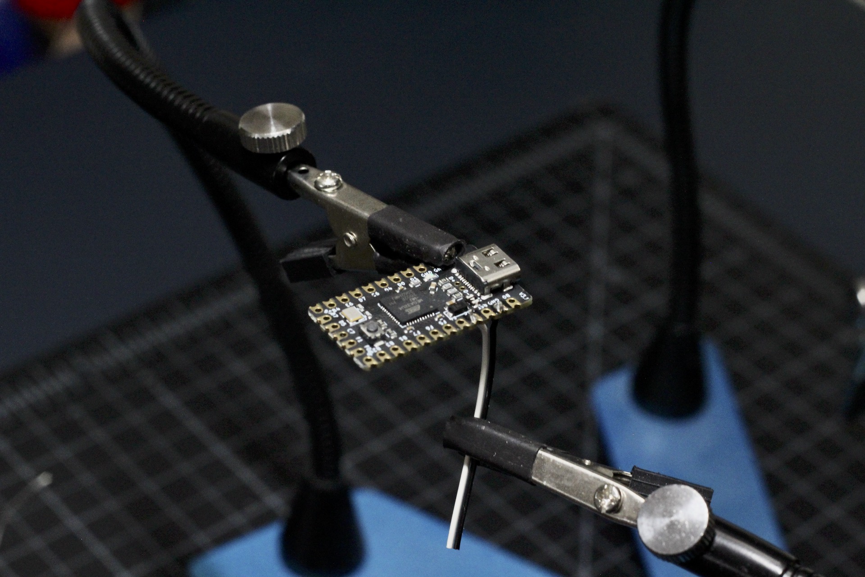
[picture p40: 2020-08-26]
photos/build_guide/aball_build_guide_10.jpeg

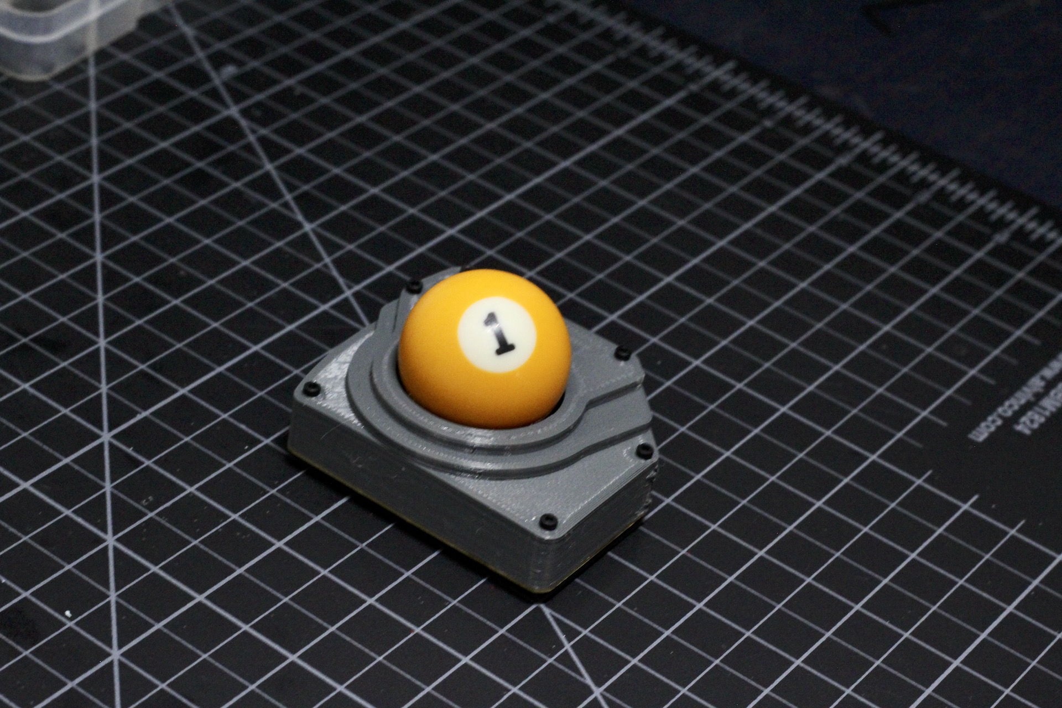
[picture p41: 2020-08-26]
photos/build_guide/aball_build_guide_22.jpeg

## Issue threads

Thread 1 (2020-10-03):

Elite C rev 4 thickness

keyboard-magpie, 2020-10-03:
Current rev of elite C is now thicker than the one used in your build, c/o the mid mount USB.

I think this needs a subtle mod to the vertical_frame.stl part. PCB is now 1.6mm thick.

I have dremelled out the slots a little, as well as reduced the height of the USB socket end of the frame.

The remainder of the case works fine with the current elite C.

Happy to work on this if fusion files could be pushed.

brickbots, 2020-10-03:
Hi  @keyboard-magpie!  Thank you so much for turning me on to this change and for providing the fitment information.  I've added a couple new STL's for the support frame to support this rev4 and also 34mm balls.

I've also included the fusion file, thanks for pointing out that I had missed including it.  Hopefully its not overly messy and can make personalizing the design easier for folks 👍

Closed 2020-10-03.

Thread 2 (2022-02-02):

X axis is inverted

pfn, 2022-02-02:
I made one!

It's pretty cool, except flashing firmware is a pain. I mention this because the X axis was reversed for me. I had to update my config.h and flash again. I flashed the latest version at https://github.com/qmk/qmk_firmware/tree/master/keyboards/handwired/aball

```c
#define POINTING_DEVICE_INVERT_X
```

It would also be nice to change the design to use an adns9800 directly than a breakout that is only available from a single vendor.

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

brickbots, 2022-02-03:
Hi Hi!

I'm really digging the ball you are using there.  It's a wonderful looking build!

Thank you so much for spotting this bug.  When I converted over to the mainline ADNS drivers I removed all my custom code, including the axis fix, and forgot to enable it in the new libs.  I really appreciate your issue report and have started a PR in the QMK repo to fix it.  I'll also upload

I know it can be expensive/difficult to source but the board from Jack enterprises makes the whole project approachable for people with limited electronics expertise.  Unfortunately, to work reliably, the ADNS generally requires some supporting circuitry.  There are some open source designs for a drop in replacement board, but it requires soldering some fairly small surface mount components and might not make sense as a one-off:
https://easyeda.com/pigboard/adns9800board

If I were to run a group buy of some sort, I'd have a more specific solution manufactured, but it'd take a bit of volume to make the economics work out.

Thanks again for sharing and spotting the bug!

pfn, 2022-02-06:
Awesome, thanks for pointing out the BOM/board design on easyeda, that's a good step forward for breaking the reliance on a single vendor of the breakout board.

roygbyte, 2022-08-03:
Been eyeing this project for a few months, possibly psyching myself up to build an aball. :)

How're you finding it now, a few months later, @pfn? Any best practices to pass along to someone waiting in the wings?

pfn, 2022-08-09:
@roygbyte aball has been working great for me, but I would like to do some minor mods that aren't really a problem of aball:
* integrate into the keyboard case for better stability
* design a case to better capture the ball from falling out
* design in a more accessible reset switch for flashing

otherwise, I use aball with my kyria daily, one of the best ergo setups for me, and the mods I described aren't really necessary to do, just something to occupy my time when I get bored.

roygbyte, 2022-08-09:
That's good to know! My dream is actually to be able to control the aball with my foot :) For me that would be ergo-bliss!

Closed 2022-02-03.

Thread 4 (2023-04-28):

Sensor gets hot and not working

lucacri, 2023-04-28:
Hey! I got the board from Jack Enterprises - ADNS-9800 Laser Motion Sensor Breakout.

My problem is that i tried to use it in QMK with a RP2040. It worked really sporadically (like 3 times) when i had it on the breadboard and I jiggled the cables in the holes a bit. Once I saw that it worked by "jiggling", I thought that if I made the connections more permanent, it'd work all the time, but I was wrong.

After soldering (and re-do it twice again from scratch), the only thing that happens is that the ADN sensor gets hot to the touch (nothing crazy, not scalding but just pretty hot) and nothing works.

I'm at my wits end, do you have _any_ suggestion on how I could proceed?

brickbots, 2023-04-28:
Yes, sounds like the 3.3 / 5v selectors might not be correct, or the jumpers have not been fully cut.  I've had a one where I thought I cut them well, but there was still continuity.  Definitely worth checking with a multimeter!

lucacri, 2023-04-28:
I didn't touch the voltage selector since the RP2040 is using 3.3v. I even added some solder on the 3.3v pads just to make sure they were all touching. Tested with multimeter and it was 3.3v

I've detached it from the RP2040 for now but I really followed the schematic on the "electronics" page, and re-did the cabling twice just to make sure i didn't make a mistake...

brickbots, 2023-04-28:
Okay, sounds like it's not a voltage select issue.  One item on the electronics diagram that could be clearer is that both the grounds needs to be bridged and connected back to the MCU.  The AG (Analog Ground) and DG (Digital Ground) are right next to each other on the sensor and need to be connected together.

It might also be worth using your phone camera to look at the sensor (try with and without the lens).  It uses IR light to illuminate the surface and most phones will show this.  It's a fair way to just see if the sensor is working and initialized.

lucacri, 2023-05-03:
@brickbots you were definitely onto something! The two ground pins (14 and 11) were not properly connected to ground:

- PIN 14 <> GND = 0 ohms
- PIN 11 <> GND = 0.659k.

I attached a jumper cable between the two, and now the mouse is moving BUT:

- it starts by going straight to the top left of the screen
- trying to move my finger on top of the sensor does move the cursor, but extremely erratically and then it jumps back to the top left

I tried everything I could in QMK: changed the ADNS9800_CLOCK_SPEED, ADNS9800_SPI_DIVISOR, pins etc but nothing changes.

Any ideas?

_also thank you all for helping me!_

brickbots, 2023-05-04:
Okay!  Getting closer.... The behavior you described reminded me of an issue another person had which they eventually solved, but not in a satisfying way.  Here's the relevant portion of the email exchange.  The behavior described sounds just like what is happening for you.  Diagonal motion to top-left of screen.

_I have an update regarding the behavior of my aball.

I compile once again the firmware through qmk msys this time and flashed it with qmk toolbox.

What I noticed this time ,(I don’t this has something to do with the way I compile the firmware) is that the aball works !!

But if I unplug the cable and plug it  again (same pc,same cable) then I get the behavior I desrcribed in the previous mails.

The cursor moves on its own and sticks to the left end of my monitor.
If I flash it again it works!!
If I restart my pc ,it’s still working._

Not sure what the lesson/take-away is from this.  I thought it might be something with the chip-select pin, but it seemed like it was soldered correctly, configured right in the source, and they did not change anything that I'm aware of to get it working.

lucacri, 2023-05-04:
Hey gang, I SOLVED IT!

Remember when I said that I soldered and resoldered the cables twice? At the time the sensor could not work because of the AG and DG grounds not being attached, no matter what I did.

I just received a new great multimeter from Aliexpress, I wanted to test it so I just checked that the SPI pins were not shorting with each other, and.... the MISO and MOSI were shorted together!!! I desoldered one of them to see if it was my cable or the traces, and it was my cable because **ONE** single strand, literally the size of a human hair, was stuck to the other solder joint!

I redid the soldering and SUCCESS! Works perfectly now!!

Thank you all for your help, without your suggestions (especially @brickbots with the ground pins idea) I would still be pulling my hair!

Closed 2023-05-04.

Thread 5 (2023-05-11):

Acrylic plates thickness

ziombo, 2023-05-11:
I currently have acces to cut acrylis plates with +/- 2mm thickness. Based on the description for acylic case, I need:
seven 3mm layers in total, not including the base piece which can either be [...] or laser cut from 1.5mm metal or acrylic.
2 x middle_a.dxf - Middle piece with no side hole
2 x middle_b.dxf - Middle piece with side reset hole
1 x top_a.dxf
1 x top_b.dxf
1 x top_c.dxf

I'm trying to wrap my head around which part should have whick thickness. Is base supposed to be 1.5mm and every other part 3mm?

brickbots, 2023-05-11:
Hi @ziombo!  Thanks for your question, I'll work to clarify that portion in the documentation.  All 7 of the layers that stack on top of the bottom piece should be 3mm thickness.  So you are aiming for a total height of about 21mm, but the hollow middle portion needs to be 12mm tall.  So if you are using 2mm stock, you'll need 3x the middle_an and 3x middle_b to make sure there is enough height to hold the mechanics.

The top pieces are less critical.  They keep the dust out and look nice, so you have more flexibility there.  You could just use the 2mm stock for 1x each piece and the top would be a bit lower-profile, but it will function the same.

For the bottom piece, it can be as thick or thin as desired.  As long as it's stiff enough, which should not be much of a problem at this size.  I think a single 2mm acrylic piece would be just fine if you didn't want to go metal for the bottom plate.

Hope this helps, please reach out with any questions!

ziombo, 2023-05-12:
Thanks for the quick reply! It does make sense now and I passed this information to the shop that will cut these parts for me. One more thing. Do you know of any alternatives for the sensor you've [linked](https://www.tindie.com/products/jkicklighter/adns-9800-laser-motion-sensor/#shipping)? I'm from Europe and ordering this for US will cost me probably just as much as the sensor and will also take long. Any Europe or China based alternatives would be appreciated as it's usually easier and cheaper to order parts this way for me. Although that's not a deal breaker so if not then I'll get the sensor from the US.

brickbots, 2023-05-12:
Happy to help!  The actual sensor package is fairly easy to get, but I did choose a breakout board which is made by a small (one person?) company in the US... which was not a great idea.  I've since started considering part availability more in my designs.....

This is a compatible open source version that you could build yourself, if you are okay with surface mount components:

https://github.com/kbjunky/ADNS9800

Not sure if this help and I definitely wish I had a better source for these sensors!

Closed 2023-05-12.

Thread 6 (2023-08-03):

Elite-Pi instead of Elite-C wiring

janradlowski, 2023-08-03:
It looks like Elite-C is being replaced with Elite-Pi which seems to be similar, but for example it's using a different controller (this should be handled by qmk convert flag), but I'm wondering if in that case the wiring for Elite-C will still work for the Pi version?

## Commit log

2020-06-13 Starting readme
    [bottom.dxf, bottom.stl, middle.dxf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]
2020-06-20 Finished BOM
2020-09-27 Added case sections
2020-09-27 Switch firmware to my branch as it's not yet merged in QMK
2020-09-30 Adding thickness for stacked case
2020-10-03 Add support for rev4/34mm ball and fusion file
    [aball_v13.f3d, vertical_frame_rev3_38mm.stl, vertical_frame_rev4_34mm.stl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]
2020-10-20 Added voltage select info
2020-10-22 Increased thickness around bearing holes in 34mm frame for stronger printing
    [aball_v13.f3d, aball_v15.f3d, vertical_frame_rev4_34mm.stl]
2021-09-12 Adjust top piece cutout for thicker elite C's
    [top.dxf]
2021-09-16 Plate case info
2024-12-21 New source for sensors
